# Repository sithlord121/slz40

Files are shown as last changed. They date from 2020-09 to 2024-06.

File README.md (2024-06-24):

# slz40
PCB and keymap files for the SLZ40, a 40s style keyboard with numbers for Zhuyin input.

The PCB requires a Pro Micro (or comparable) controller as well as 58 diodes, 58 MX style switches

The sandwich case takes M2 screws and standoffs.

You can find the key caps required in the following layout.

cap size | number | R1 | R2 | R3 | R4 | R5
-------|-------|-------|-------|------|------|-------|
1u | 47 | 11 | 13 | 10 | 10 | 3 |
1.25u | 6 | 0 | 0 | 1 | 1 | 4 |
1.5u | 1 | 0 | 0 | 0 | 0 | 1 |
1.75u | 4 | 0 | 0 | 1 | 1 | 2 |



[QMK toolbox](https://docs.qmk.fm/#/) is required to flash the layout 

The default keymap can be found in the keymap folder.

A hex of the default layout can be found [here](slz40_default.hex) to make sure the keyboard is working.

--
Update 6/24/2024
Added firmware for Via/Vial compatability.

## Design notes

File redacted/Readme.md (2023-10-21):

This is a one-shot version of the SLZ40.
The idea is to fit the SLZ in a standard 60% case.
The compromise that had to be made was that the top right key had to be moved to accomodate the case stand.

The PCB has the MCU and other components soldered.
This is the repository for the .json file to create custom keymaps as well as a default layout.

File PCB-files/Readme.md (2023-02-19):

Files needed to print the PCB and sandwich case can be found here

2/7/2023:
Added choc version files.
Firmware is the same.

2/18/2023:
Verified choc version uses the same version of the firmware.

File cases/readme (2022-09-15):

These are case files for cases for the SLZ40

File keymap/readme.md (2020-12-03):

# slz40

slz40

*A short description of the keyboard/project*

* Keyboard Maintainer: [SithLord](https://github.com/sithlord121/slz40)
* Hardware Supported: *The PCBs, controllers supported*
* Hardware Availability: *Links to where you can find this hardware*

Make example for this keyboard (after setting up your build environment):

    qmk compile -kb slz40 -km default

Flash use QMK Toolbox

See the [build environment setup](https://docs.qmk.fm/#/getting_started_build_tools) and the [make instructions](https://docs.qmk.fm/#/getting_started_make_guide) for more information. Brand new to QMK? Start with our [Complete Newbs Guide](https://docs.qmk.fm/#/newbs).

There is no physical reset button so be sure to map a key in your keymap

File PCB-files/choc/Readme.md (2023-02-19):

Choc version files can be found here

Thanks to Phoenix#2490 from the Discord 40% server for helping with the design.

2/18/2023: Modified bottom plate. Added cutout to allow NetDot Gen10 dongle to be used.

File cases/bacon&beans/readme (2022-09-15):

This is a 3D print-able two piece case with open bottom in the IBM Model M style
Switch plate is integrated into top part. 

Case designed by Bacon&Beans from the 40% server.

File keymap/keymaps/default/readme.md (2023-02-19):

# The default keymap for slz40

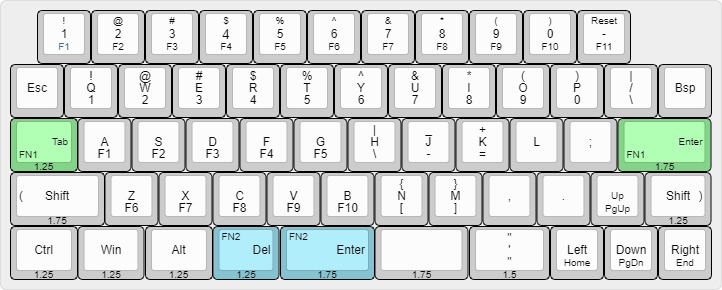
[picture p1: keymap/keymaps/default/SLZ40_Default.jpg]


The green keys are tap/hold for fn1 layer, the blue keys are tap/hold for fn2 layer

Remember to map a reset key in your keymap. Otherwise you will have to access the reset key physically to flash a new keymap.

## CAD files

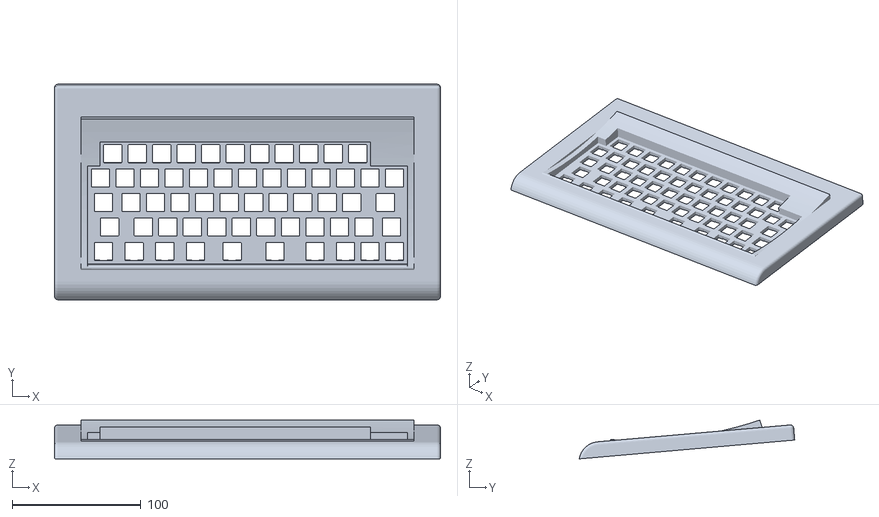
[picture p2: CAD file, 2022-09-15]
cases/bacon&beans/Top_SLZ40_ModelM.stl
300.0 x 167.6 x 30.1

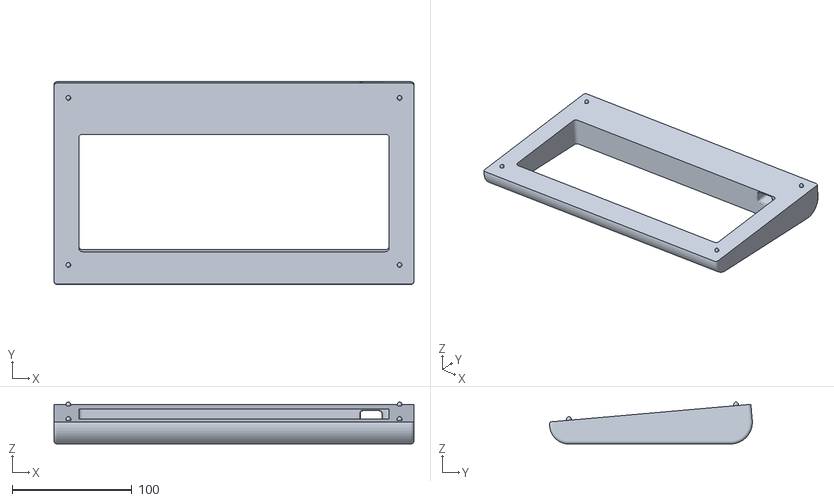
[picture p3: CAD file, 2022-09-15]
cases/bacon&beans/Bottom_SLZ40_ModelM.stl
300.0 x 169.0 x 35.0

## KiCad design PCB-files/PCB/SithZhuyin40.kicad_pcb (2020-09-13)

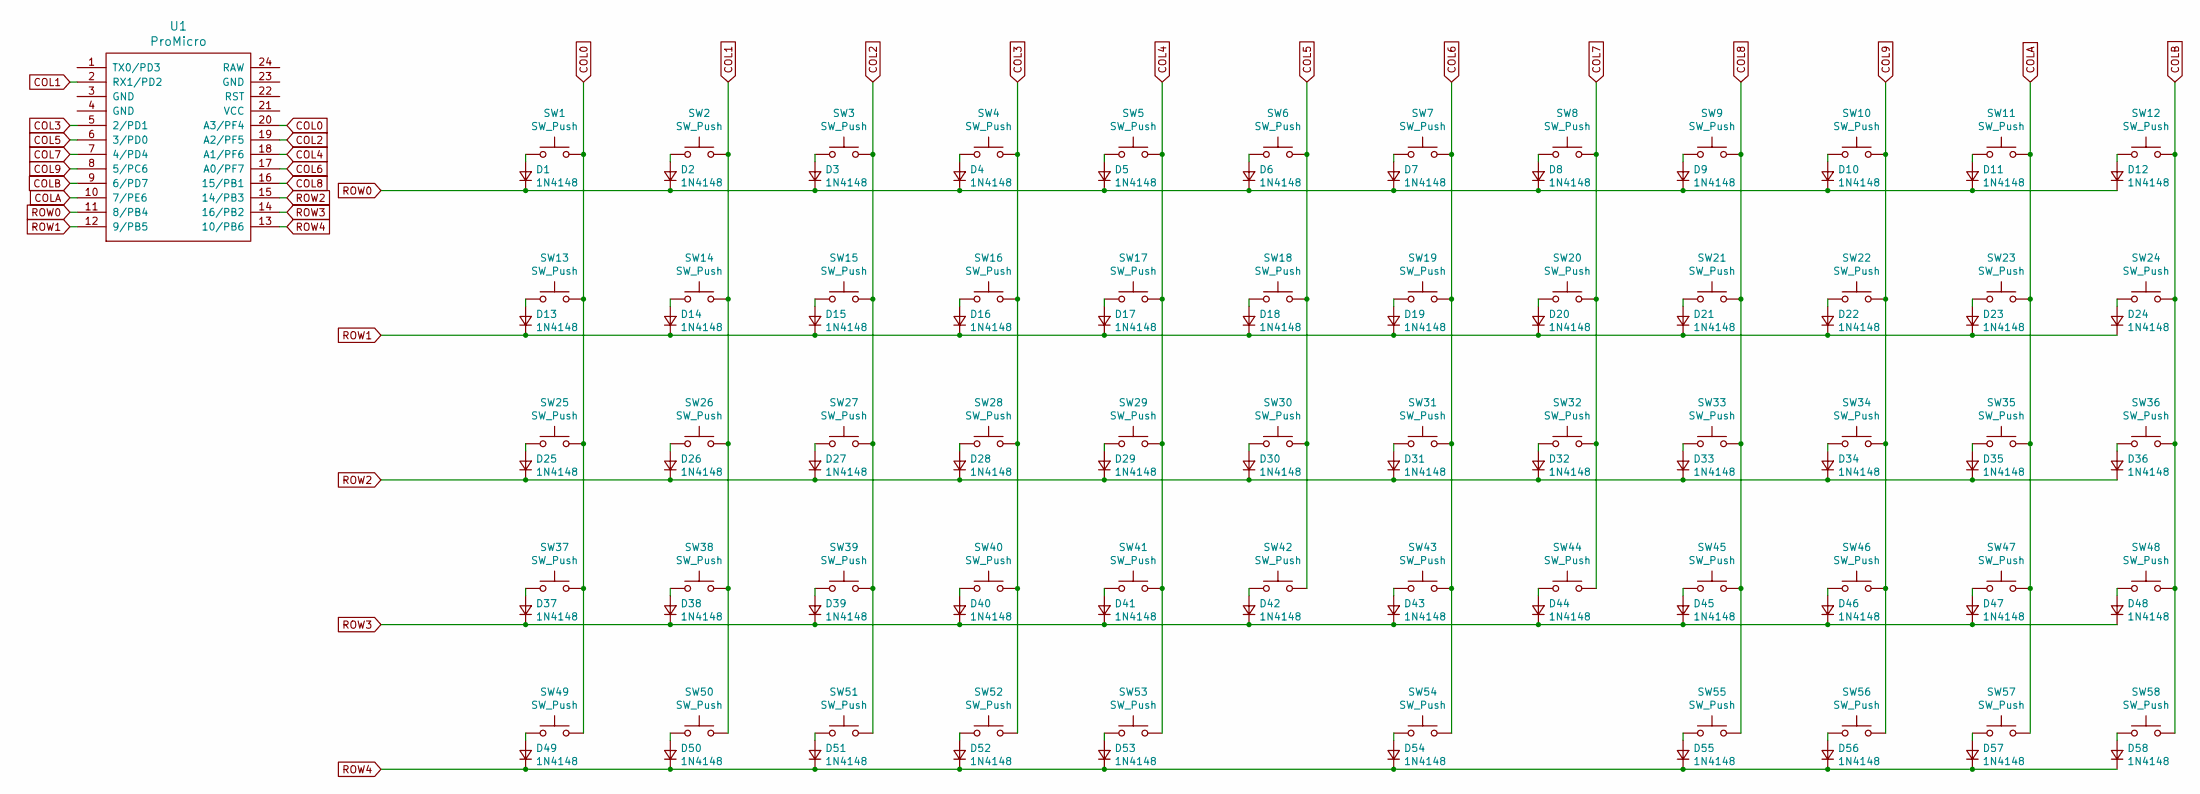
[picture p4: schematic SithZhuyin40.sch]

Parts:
D1, D2, D3, D4, D5, D6, D7, D8, D9, D10, D11, D12, D13, D14, D15, D16, D17, D18, D19, D20, D21, D22, D23, D24, D25, D26, D27, D28, D29, D30, D31, D32, D33, D34, D35, D36, D37, D38, D39, D40, D41, D42, D43, D44, D45, D46, D47, D48, D49, D50, D51, D52, D53, D54, D55, D56, D57, D58: 1N4148; Diode-Hybrid-Back
SW1, SW2, SW3, SW4, SW5, SW6, SW7, SW8, SW9, SW10, SW11, SW12, SW13, SW14, SW15, SW16, SW17, SW18, SW19, SW20, SW21, SW22, SW23, SW24, SW26, SW27, SW28, SW29, SW30, SW31, SW32, SW33, SW34, SW35, SW38, SW39, SW40, SW41, SW42, SW43, SW44, SW45, SW46, SW47, SW56, SW57, SW58: SW_Push; MXOnly-1U-NoLED
SW25, SW48, SW49, SW50, SW51, SW52: SW_Push; MXOnly-1.25U-NoLED
SW36, SW37, SW53, SW54: SW_Push; MXOnly-1.75U-NoLED
SW55: SW_Push; MXOnly-1.5U-NoLED
U1: ProMicro; ArduinoProMicro-BackSide

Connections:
COL0: SW1.2, SW13.2, SW25.2, SW37.2, SW49.2, U1.20 (A3/PF4)
COL1: SW2.2, SW14.2, SW26.2, SW38.2, SW50.2, U1.2 (RX1/PD2)
COL2: SW3.2, SW15.2, SW27.2, SW39.2, SW51.2, U1.19 (A2/PF5)
COL3: SW4.2, SW16.2, SW28.2, SW40.2, SW52.2, U1.5 (2/PD1)
COL4: SW5.2, SW17.2, SW29.2, SW41.2, SW53.2, U1.18 (A1/PF6)
COL5: SW6.2, SW18.2, SW30.2, SW42.2, U1.6 (3/PD0)
COL6: SW7.2, SW19.2, SW31.2, SW43.2, SW54.2, U1.17 (A0/PF7)
COL7: SW8.2, SW20.2, SW32.2, SW44.2, U1.7 (4/PD4)
COL8: SW9.2, SW21.2, SW33.2, SW45.2, SW55.2, U1.16 (15/PB1)
COL9: SW10.2, SW22.2, SW34.2, SW46.2, SW56.2, U1.8 (5/PC6)
COLA: SW11.2, SW23.2, SW35.2, SW47.2, SW57.2, U1.10 (7/PE6)
COLB: SW12.2, SW24.2, SW36.2, SW48.2, SW58.2, U1.9 (6/PD7)
unnamed: D1.2 (A), SW1.1
unnamed: D2.2 (A), SW2.1
unnamed: D3.2 (A), SW3.1
unnamed: D4.2 (A), SW4.1
unnamed: D5.2 (A), SW5.1
unnamed: D6.2 (A), SW6.1
unnamed: D7.2 (A), SW7.1
unnamed: D8.2 (A), SW8.1
unnamed: D9.2 (A), SW9.1
unnamed: D10.2 (A), SW10.1
unnamed: D11.2 (A), SW11.1
unnamed: D12.2 (A), SW12.1
unnamed: D13.2 (A), SW13.1
unnamed: D14.2 (A), SW14.1
unnamed: D15.2 (A), SW15.1
unnamed: D16.2 (A), SW16.1
unnamed: D17.2 (A), SW17.1
unnamed: D18.2 (A), SW18.1
unnamed: D19.2 (A), SW19.1
unnamed: D20.2 (A), SW20.1
unnamed: D21.2 (A), SW21.1
unnamed: D22.2 (A), SW22.1
unnamed: D23.2 (A), SW23.1
unnamed: D24.2 (A), SW24.1
unnamed: D25.2 (A), SW25.1
unnamed: D26.2 (A), SW26.1
unnamed: D27.2 (A), SW27.1
unnamed: D28.2 (A), SW28.1
unnamed: D29.2 (A), SW29.1
unnamed: D30.2 (A), SW30.1
unnamed: D31.2 (A), SW31.1
unnamed: D32.2 (A), SW32.1
unnamed: D33.2 (A), SW33.1
unnamed: D34.2 (A), SW34.1
unnamed: D35.2 (A), SW35.1
unnamed: D36.2 (A), SW36.1
unnamed: D37.2 (A), SW37.1
unnamed: D38.2 (A), SW38.1
unnamed: D39.2 (A), SW39.1
unnamed: D40.2 (A), SW40.1
unnamed: D41.2 (A), SW41.1
unnamed: D42.2 (A), SW42.1
unnamed: D43.2 (A), SW43.1
unnamed: D44.2 (A), SW44.1
unnamed: D45.2 (A), SW45.1
unnamed: D46.2 (A), SW46.1
unnamed: D47.2 (A), SW47.1
unnamed: D48.2 (A), SW48.1
unnamed: D49.2 (A), SW49.1
unnamed: D50.2 (A), SW50.1
unnamed: D51.2 (A), SW51.1
unnamed: D52.2 (A), SW52.1
unnamed: D53.2 (A), SW53.1
unnamed: D54.2 (A), SW54.1
unnamed: D55.2 (A), SW55.1
unnamed: D56.2 (A), SW56.1
unnamed: D57.2 (A), SW57.1
unnamed: D58.2 (A), SW58.1
ROW0: D1.1 (K), D2.1 (K), D3.1 (K), D4.1 (K), D5.1 (K), D6.1 (K), D7.1 (K), D8.1 (K), D9.1 (K), D10.1 (K), D11.1 (K), D12.1 (K), U1.11 (8/PB4)
ROW1: D13.1 (K), D14.1 (K), D15.1 (K), D16.1 (K), D17.1 (K), D18.1 (K), D19.1 (K), D20.1 (K), D21.1 (K), D22.1 (K), D23.1 (K), D24.1 (K), U1.12 (9/PB5)
ROW2: D25.1 (K), D26.1 (K), D27.1 (K), D28.1 (K), D29.1 (K), D30.1 (K), D31.1 (K), D32.1 (K), D33.1 (K), D34.1 (K), D35.1 (K), D36.1 (K), U1.15 (14/PB3)
ROW3: D37.1 (K), D38.1 (K), D39.1 (K), D40.1 (K), D41.1 (K), D42.1 (K), D43.1 (K), D44.1 (K), D45.1 (K), D46.1 (K), D47.1 (K), D48.1 (K), U1.14 (16/PB2)
ROW4: D49.1 (K), D50.1 (K), D51.1 (K), D52.1 (K), D53.1 (K), D54.1 (K), D55.1 (K), D56.1 (K), D57.1 (K), D58.1 (K), U1.13 (10/PB6)

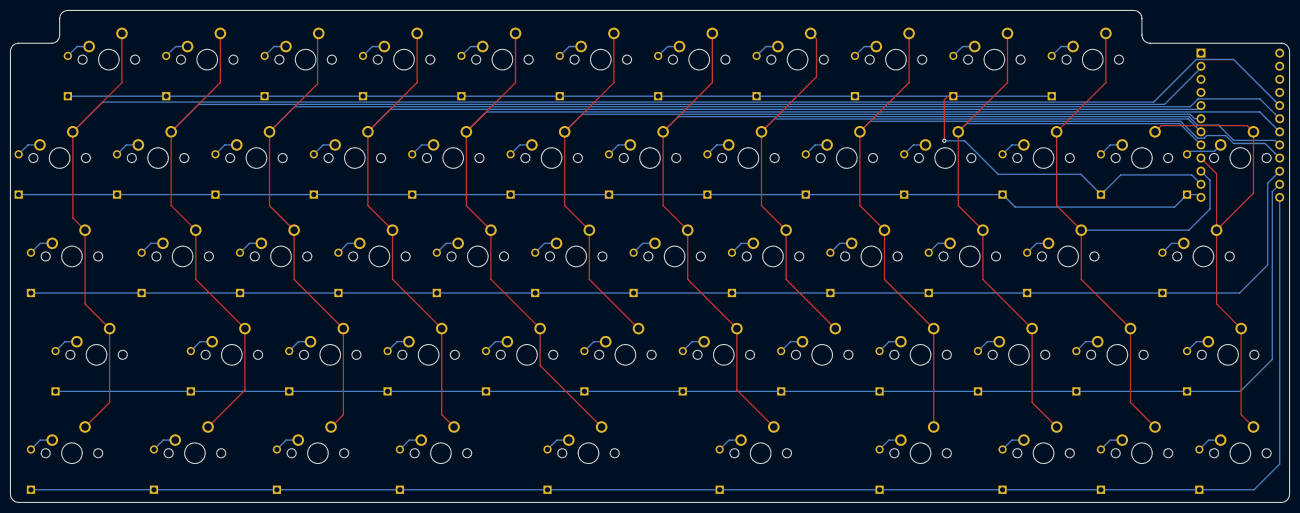
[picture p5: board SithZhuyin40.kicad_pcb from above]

Board: 2 copper layers, 247.7 x 95.3 mm, 117 parts (0 on the bottom side), 75 nets.

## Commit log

2020-09-13 Add files via upload
    PCB files. No silkscreen.
    [SithZhuyin40-B_Cu.gbr, SithZhuyin40-B_Mask.gbr, SithZhuyin40-B_Paste.gbr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]
2023-02-20 Delete Bottom.zip
    zip file includes an old version of the gerber, which may be confusing.
